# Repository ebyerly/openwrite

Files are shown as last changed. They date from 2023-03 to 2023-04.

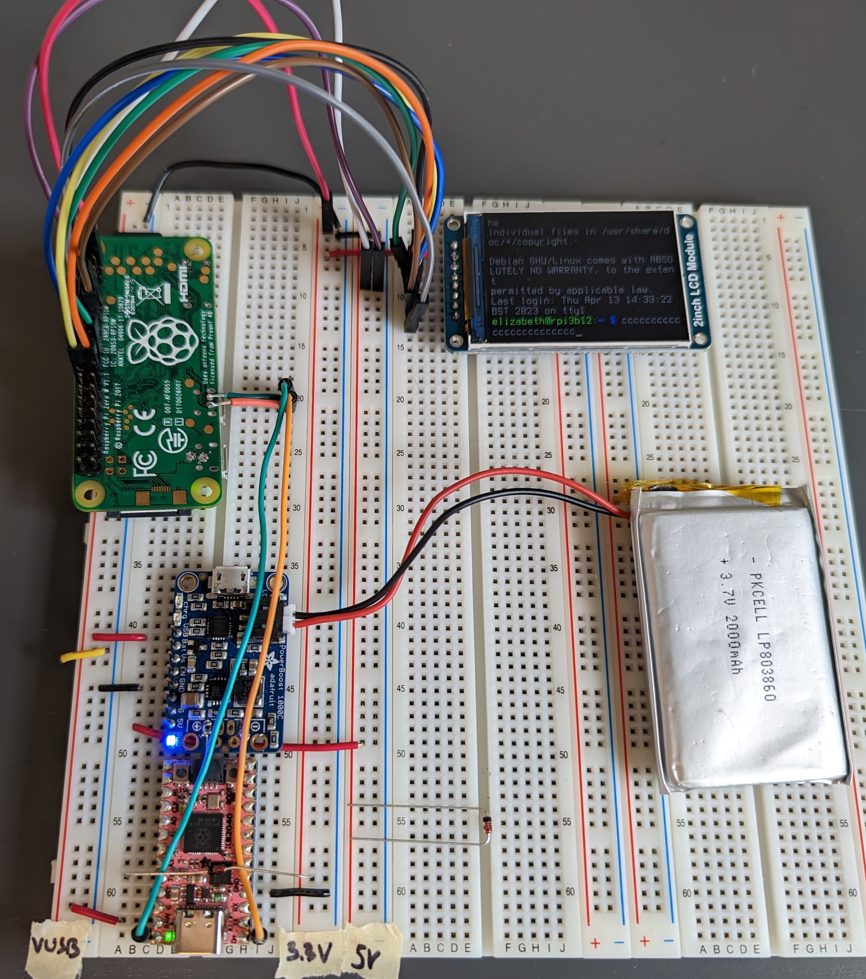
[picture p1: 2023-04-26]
kicad/breadboard.jpg

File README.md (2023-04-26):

# openwrite

DIY alternative to https://getfreewrite.com/ because I love the concept and the execution and can't justify the price.

### Requirements

* write text files
* manage (switch between, copy, delete) multiple text files
* store N kB of text files
* sync text files with Google Drive folder
* 4 hours of active typing time
* rechargeable
* mechanical keyboard
* able to see last N typed words
* able to see system state (turned on, current file, etc)
* NOT able to do my typical time wasters (email, reddit, twitter) in an enjoyable way
* cheap, given the above constraints

### Outline

* terminal-only linux
* raspberry pi zero W
* Raspbian Lite
* tiniest screen that's still legible
* rechargeable battery
* single PCB mount

### Notes

#### decisions

* [X] software: QMK, KiCAD, OpenSCAD
* [X] switches: Nuphy Wisteria / Gateron KS-33
* [X] computer: Raspberry Pi Zero W v1.1
* [X] microcontroller for keyboard control: Adafruit KB2040 (https://github.com/adafruit/Adafruit-KB2040-PCB, https://github.com/drewgates/kb2040-kicad)
* [X] keycap dimensions and gap: 19mm between lead centers (cap standard is ~18mm)
* [X] power management: Adafruit PowerBoost 1000C (overkill, but I already own it)
* [X] key layout: in flux, but 5x14 ortholinear to match Moonlander to start
* [X] display: Waveshare 2" display ($15, https://www.waveshare.com/2inch-lcd-module.htm)

#### iterations

* charge/boost/buck functionality directly on the board (replace the Powerboost 1000C)
* Keyboard microcontroller directly on the board (replace the KB2040)
* integrated touchpad (https://www.cirque.com/glidepoint-circle-trackpads)
* microcontroller-powered text editor (move closer to alphasmart)
* RPiZ supports HDMI output / hot-swap boot micro-SD with regular RaspbianOS (move closer to a portable work station)
  - unclear if feasible: integrate usb-c hub so RPiZ can interface with my existing desk setup
* E-ink screen
* Add USB switching logic so switching the keyboard output doesn't require reseting the device (e.g. TS3USB221A, USB mux/demux that supports 2 upstream devices and one downstream device)
* Hotswap sockets (Mill-Max 3305-0-15-80)

#### reference projects

* through-hole pcb-mounted-microcontroller usb-c keyboard (discipline): https://github.com/coseyfannitutti/discipline
* through-hole pcb-mounted-microcontroller usb-c keyboard (framework): https://github.com/stevennguyen/framework
* mini computer with custom keyboard (penkesu): https://github.com/penk/penkesu
* system76 launch keyboard with integrated USB hub: https://github.com/system76/launch
* Env-KB, a Raspberry Pi Pico keyboard: https://github.com/Envious-Data/Env-KB
* cyberdetox rpi400 mod: https://www.reddit.com/r/cyberDeck/comments/11tzifa/new_cyberdetox_displat_for_raspberry_pi_400/
* GreatScott DIY charge/boost: https://www.youtube.com/watch?v=Fj0XuYiE7HU, https://www.instructables.com/DIY-LiPo-ChargeProtect5V-Boost-Circuit/

#### kicad

* intro to kicad by hymel/digikey: https://www.youtube.com/playlist?list=PL3bNyZYHcRSUhUXUt51W6nKvxx2ORvUQB
* getting to blink 5.0 by conceptual electronics: https://www.youtube.com/playlist?list=PLy2022BX6EspFAKBCgRuEuzapuz_4aJCn
* schematic simulation / SPICE integration: https://www.kicad.org/discover/spice/
* visually interesting circuit simulator with lots of examples: https://www.falstad.com/circuit/circuitjs.html
* https://blog.oshpark.com/2020/10/08/kicad-3d-viewer-can-now-render-after-dark/
* https://github.com/sethhillbrand/kicad_templates - includes OSH Park 2 layer (apparently validated by their team!)

#### random

* "A simple guide to electronics components" - https://www.youtube.com/watch?v=6Maq5IyHSuc
* https://datasheets.raspberrypi.com/rp2040/hardware-design-with-rp2040.pdf
* microcontroller socketing: https://docs.splitkb.com/hc/en-us/articles/360011263059-How-do-I-socket-a-microcontroller-
* https://www.youtube.com/watch?v=ezk02GJ9iMs
* https://ergogen.cache.works/
* https://wiki.ai03.com/books/pcb-design/page/pcb-guide-part-1---preparations
* https://learn.adafruit.com/pigrrl-zero - guide to create a Pi Zero powered gaming device, includes step-by-step on connecting battery and display.
* http://i.imgur.com/ZQHDGTV.jpg
* https://sudomod.com/forum/viewtopic.php?t=2666
* https://cdn.sparkfun.com/assets/learn_tutorials/6/7/6/PiZero_1.pdf
* https://www.neverstopbuilding.com/blog/wiring-micro-usb-pinout
* https://en.wikipedia.org/wiki/USB
* https://desertbot.io/blog/headless-pi-zero-w-wifi-setup-windows
* OpenSCAD libraries/models:
  - https://github.com/revarbat/BOSL
  - https://www.thingiverse.com/thing:1638529
  - https://www.thingiverse.com/thing:2186550
* Part dimension sources
  - https://learn.adafruit.com/adafruit-2-2-pitft-hat-320-240-primary-display-for-raspberry-pi/downloads
  - https://learn.adafruit.com/adafruit-powerboost-1000c-load-share-usb-charge-boost/downloads
  - https://www.raspberrypi.org/documentation/hardware/raspberrypi/mechanical/rpi_MECH_Zero_1p3.pdf

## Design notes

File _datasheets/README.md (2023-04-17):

Storing links to datasheet, symbol, and footprint sources. Resources that aren't publicly accessible (no login required) and without an obvious sharing license are omitted from the folder, but linked below if found.

* https://datasheets.raspberrypi.com/
* https://componentsearchengine.com/part-view/M2042LL2W03/NKK%20Switches
* https://www.alibaba.com/product-detail/GATERON-KS-33-brown-red-blue_1600325134109.html
* https://learn.adafruit.com/adafruit-powerboost-1000c-load-share-usb-charge-boost/downloads
* https://learn.adafruit.com/adafruit-kb2040/downloads

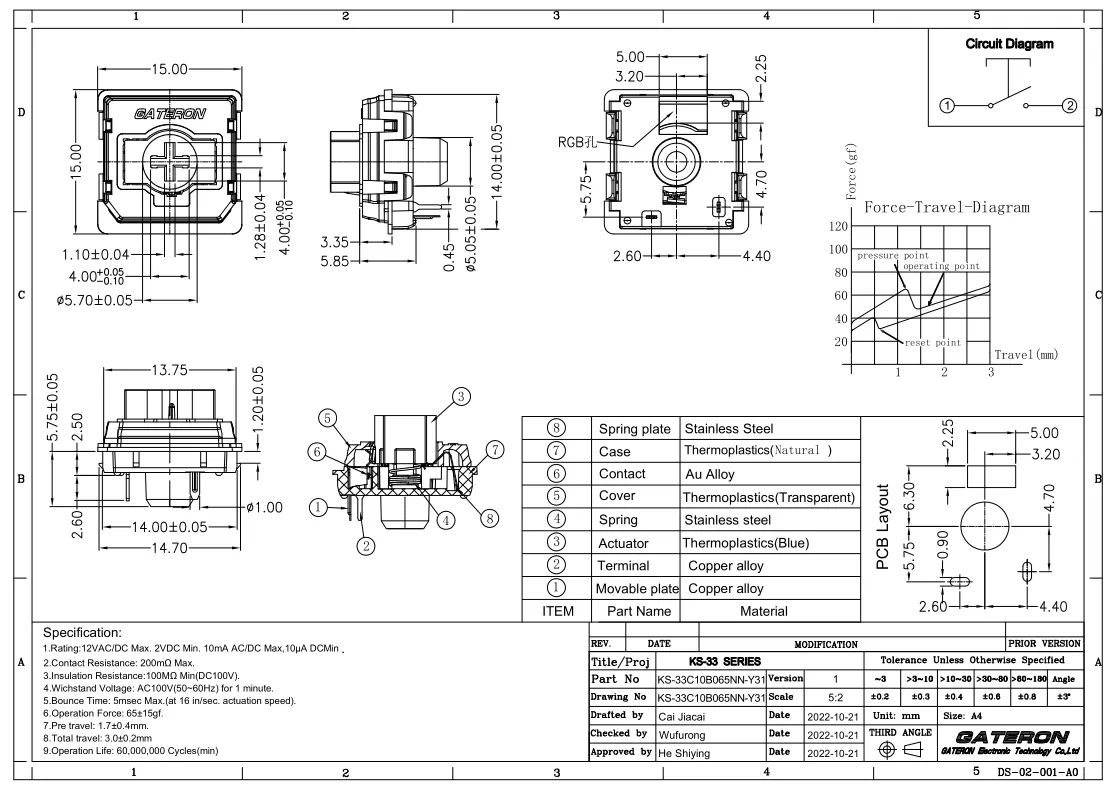
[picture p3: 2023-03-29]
_datasheets/gateron_ks-33.png

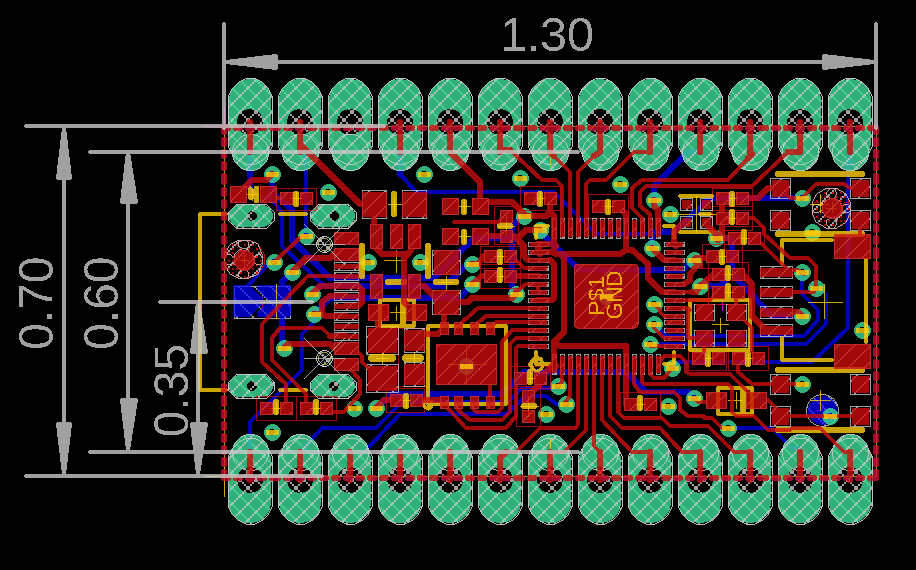
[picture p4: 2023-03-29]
_datasheets/KeeBoar_fabprint.png

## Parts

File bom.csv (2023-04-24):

part | manufacturer | price | link | purpose | notes
KS-33 (Wisteria) | Gateron | $38.50/100 | https://nuphy.com/collections/switches/products/nuphy-wisteria-t55-switches | keyboard switches | X
Raspberry Pi Zero W | X | $10 | https://www.adafruit.com/product/3400 | Onboard computer | X
PowerBoost 1000 Charger | Adafruit | $19.95 | https://www.adafruit.com/product/2465 | Manage LiPo and onboard computer power | Rechargeable 5V Lipo USB Boost @ 1A - https://github.com/adafruit/Adafruit-PowerBoost-1000C
KB2040 | Adafruit | $8.95 | https://www.adafruit.com/product/5302 | Keyboard driver | https://github.com/adafruit/Adafruit-KB2040-PCB
2in LCD ST7789v | Waveshare | $14.75 | https://www.amazon.com/2inch-IPS-LCD-Display-Module/dp/B082GFTZQD | Screen/display | https://www.waveshare.com/wiki/2inch_LCD_Module
16Gb MicroSD (generic) | N/A | ~$7 | https://www.google.com/search?q=16gb+microsd | Onboard computer storage | X
EG1218 | E-Switch | $0.65 | https://www.digikey.com/en/products/detail/e-switch/EG1218/101726 | On/Off switch for onboard computer power | X
BK-18650-PC2 | MPD | $3.75 | https://www.digikey.com/en/products/detail/mpd-memory-protection-devices/BK-18650-PC2/2079908 | 18650 battery holder | X
PRT-12895 | SparkFun | $6.62 | https://www.digikey.com/en/products/detail/sparkfun-electronics/PRT-12895/5271298 | 2.6Ah 18650 battery | X
JST PH 2-Pin Cable - Female | Adafruit | $0.75 | https://www.adafruit.com/product/261 | Connect powerboost to board/battery | X

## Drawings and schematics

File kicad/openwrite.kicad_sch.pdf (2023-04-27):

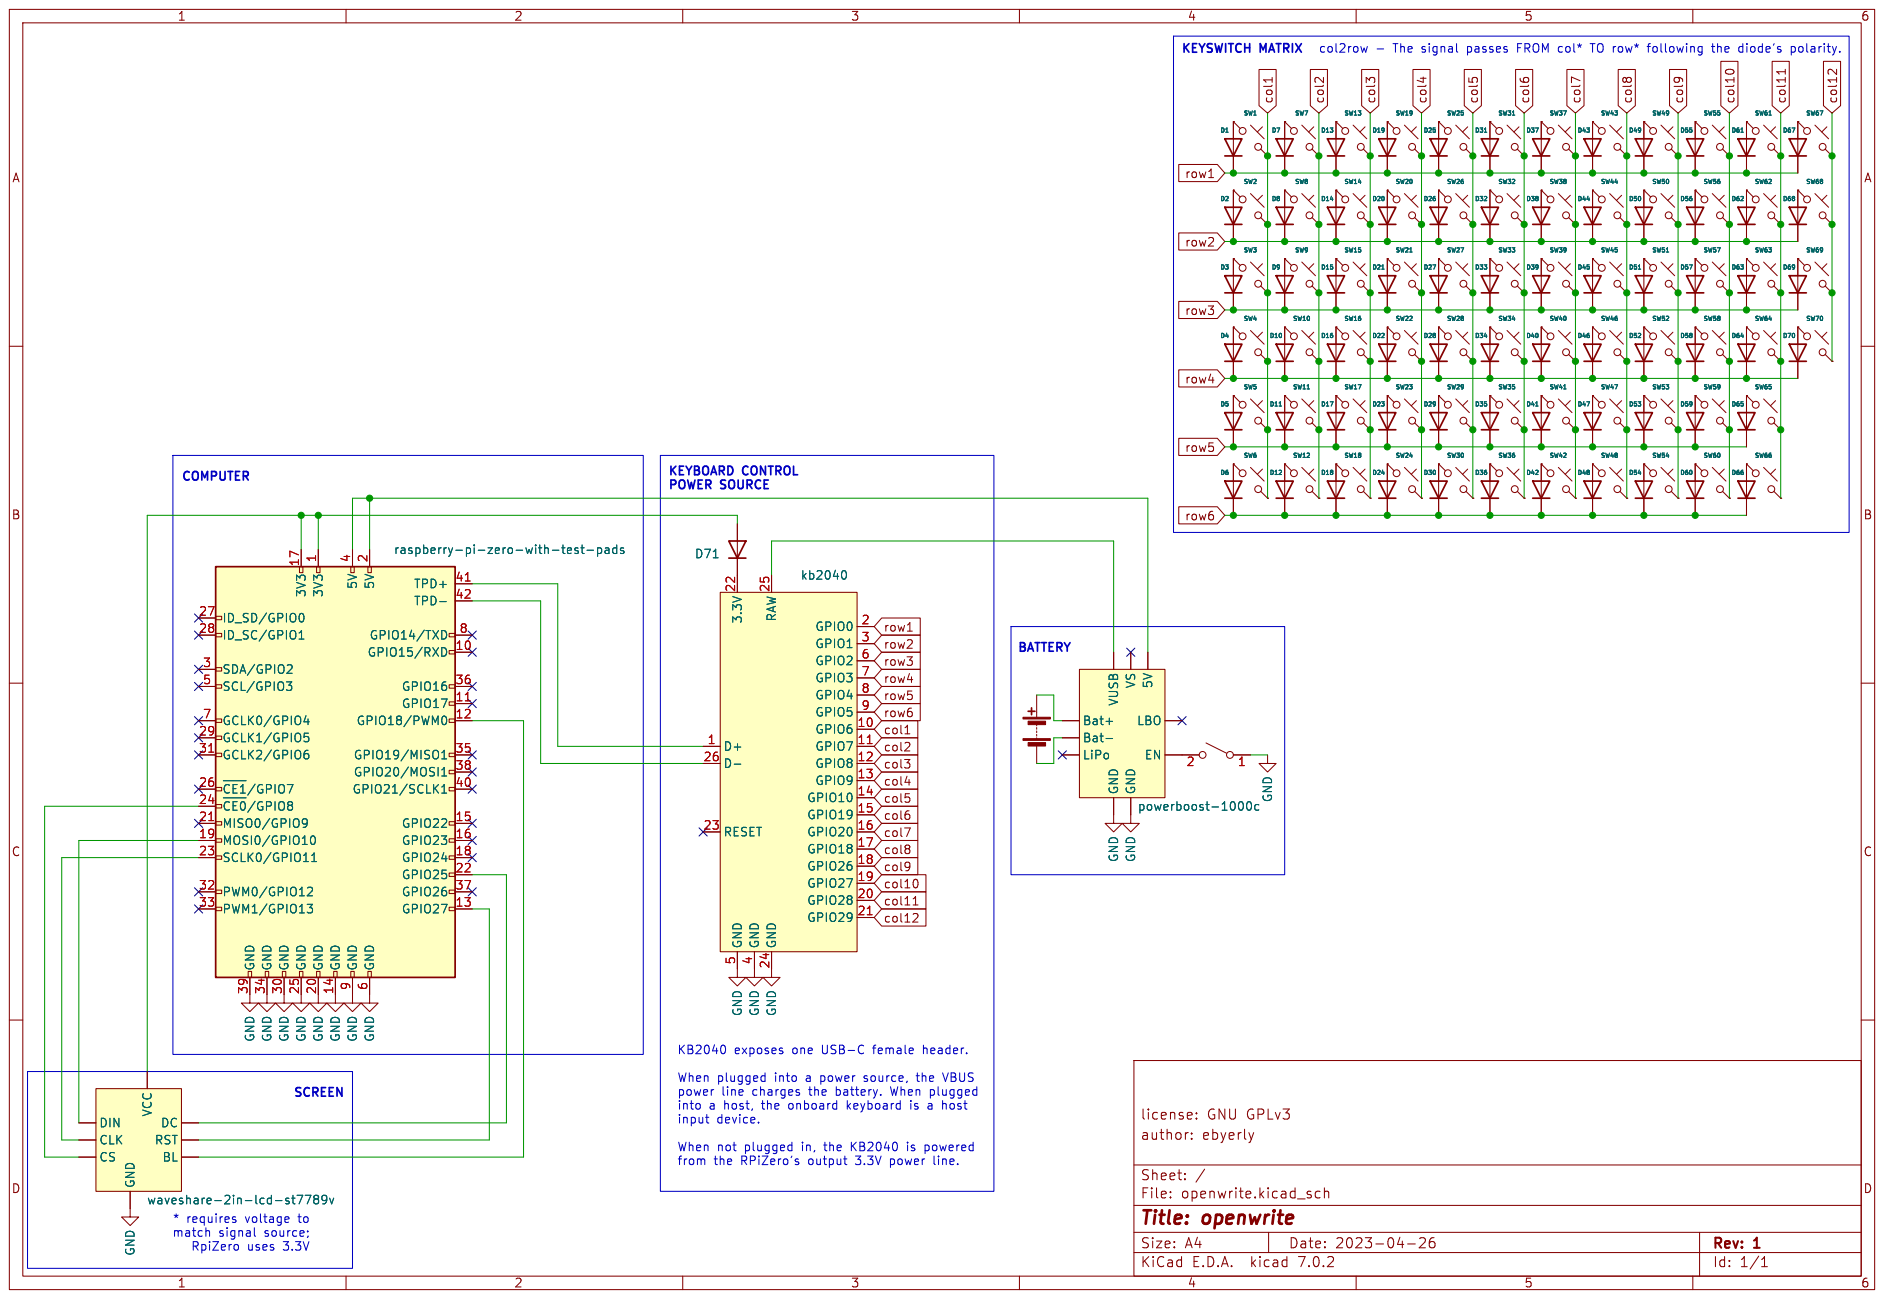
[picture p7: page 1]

KEYSWITCH MATRIX KEYBOARD CONTROL POWER SOURCE
SW32 GND

4 GPIO21/SCLK1 40 TPD+ 41 TPD- 42 SCL/GPIO3 5 GND

raspberry-pi-zero-with-test-pads 3V3

raspberry-pi-zero-with-test-pads

5 GPIO2 6 GPIO3 7 GPIO4 8 GPIO5 9 GND GND GND GND

row5 KB2040 exposes one USB-C female header. When plugged into a power source, the VBUS

power line charges the battery. When plugged
into a host, the onboard keyboard is a host
input device. When not plugged in, the KB2040 is powered

license: GNU GPLv3
File: openwrite.kicad_sch Sheet: / author: ebyerly

from the RPiZero's output 3.3V power line.

waveshare-2in-lcd-st7789v
* requires voltage to match signal source; RpiZero uses 3.3V

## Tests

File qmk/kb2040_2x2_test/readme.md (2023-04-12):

# kb2040_2x2_test

kb2040_2x2_test

*A short description of the keyboard/project*

* Keyboard Maintainer: [ebyerly](https://github.com/ebyerly)
* Hardware Supported: *The PCBs, controllers supported*
* Hardware Availability: *Links to where you can find this hardware*

Make example for this keyboard (after setting up your build environment):

    make kb2040_2x2_test:default

Flashing example for this keyboard:

    make kb2040_2x2_test:default:flash

See the [build environment setup](https://docs.qmk.fm/#/getting_started_build_tools) and the [make instructions](https://docs.qmk.fm/#/getting_started_make_guide) for more information. Brand new to QMK? Start with our [Complete Newbs Guide](https://docs.qmk.fm/#/newbs).

## Bootloader

Enter the bootloader in 3 ways:

* **Bootmagic reset**: Hold down the key at (0,0) in the matrix (usually the top left key or Escape) and plug in the keyboard
* **Physical reset button**: Briefly press the button on the back of the PCB - some may have pads you must short instead
* **Keycode in layout**: Press the key mapped to `QK_BOOT` if it is available

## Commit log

2020-05-25 Initial commit; base plate generator and Powerboost 1000C base plate
    [generic_base_plate.scad, power_boost_1000_base_plate.scad]
2023-03-06 base plates for printed parts Still pending keyboard and battery holder
    [adafruit_pitft_22_hat_base_plate.scad, generic_base_plate.scad, power_boost_1000_base_plate.scad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]
2023-03-14 refactor notes, move towards custom pcb
    [adafruit_pitft_22_hat_base_plate.scad, bosl2_tutorials.scad, generic_base_plate.scad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]
2023-03-15 Update notes.md
    add kicad tutorial links
2023-03-19 initialize kicad project with osh park constraints
    [openwrite.kicad_pcb, openwrite.kicad_sch]
2023-03-21 more notes and kicad project tweaks
    [openwrite.kicad_pcb]
2023-03-21 More notes, ignore kicad backups
2023-03-29 Refactor towards final format
    [adafruit_pitft_22_hat_base_plate.scad, bom.csv, bosl2_tutorials.scad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]
2023-03-30 component ideas for digital usb switching
2023-04-17 Gateron KS-33 footprint
2023-04-22 footprints and schematics
2023-04-22 Updated footprints for kb2040 and powerboost 1000c
2023-04-24 Symbols associated with footprints
    [bom.csv]
2023-04-24 csv typo
    [bom.csv]
2023-04-25 First draft of schematic
    [openwrite.kicad_sch]
2023-04-25 clean up schema, fix typos
    [openwrite.kicad_sch]
2023-04-25 export schematic fixes to pdf/svg
2023-04-26 fix gateron-ks-33-diode symbol to remove extra pin
    [openwrite.kicad_sch]
2023-04-26 Differentiate diode and keyswitch
    [openwrite.kicad_sch]
2023-04-27 row connected to all row elements
    [openwrite.kicad_sch]
